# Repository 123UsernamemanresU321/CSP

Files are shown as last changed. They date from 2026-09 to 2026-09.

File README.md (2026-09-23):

# HEX-200 - detailed hexagonal piezoelectric tile concept

Revision A / 22 September 2026 / HBIS Collaborative Sciences Project

The regular hexagon is **200 mm across opposite flats**, 230.940 mm across
opposite corners and 50 mm high. This interpretation of “20 cm width” was an
explicit design assumption. The moving cover has a 2 mm downstroke.

## Start here

- `HEX_200_Interactive.html`: offline interactive 3D assembly. Open the downloaded
  file in a current desktop browser with WebGL 2. Rotate, zoom, inspect components,
  remove the cover, section the housing, separate components, or adjust the two
  illustrative motion controls. All scripts and meshes are embedded; no server
  or internet connection is required. File-preview apps may not execute HTML.
- `HEX_200_Technical_Design.pdf`: nine illustrated pages with dimensions, section,
  mechanism, calculations, circuit connections, materials, assembly and limits.
- `CAD/HEX_200_Assembly.step`: the editable solid assembly. **Units: millimetres.**
  This is the authoritative nominal shape representation.
- `HEX_200_Assembly.glb`: coloured visual 3D model. Its world scale is **metres**,
  as required by glTF. The root applies 0.001 to CAD coordinates in millimetres.
- `CAD/*.step`: representative individual components. Repeated parts are included
  at their first assembly location; the complete STEP contains every instance.
- `meshes/*.stl`: representative display / fit-study meshes in **mm**. Parts retain
  their assembly coordinates. These files do not qualify a printed part for loads.
- `CAD/Cover_Plate_Reference.dxf`: cover outline, 18 through holes and countersink
  reference circles in mm. Layer names distinguish through and reference geometry.
  This is a reference drawing, not a released laser/CNC job.
- `Cover_Hole_Coordinates.csv`: exact nominal XY coordinates of all 18 cover holes.
- `BOM.csv`, `parts_manifest.json`: 142 component records, materials and notes.
- `Electrical_Connections.csv`: reference circuit connectivity, not a SPICE model
  or PCB manufacturing file.
- `geometry_validation.json`: verification scope and nominal results.
- `figures/`: CAD-derived assembled, inside, exploded and cartridge renderings.

## Mechanism

The cover carries three PZT/brass bimorph beams. Their tip masses lag when the
cover accelerates, creating bending and an electrical response. Three springs
return the cover; six separate aluminium stop pillars carry the foot load after
2 mm of travel. Moving cages constrain relative tip motion. Three separate bridge
rectifiers feed a shared DC bus and a reference LTC3588-1 regulator circuit.

Cover stroke and beam deflection are independent quantities. The viewer’s beam
control is a geometric illustration, not a dynamic simulation or predicted
response. ±0.45 mm refers to total tip-centre displacement from the nominal flat
beam, including any static offset; it is not extra travel on top of gravity sag.

## Accuracy and verification

- All 142 CAD component shapes are valid in OpenCascade.
- The nominal rigid-part check found no unintended overlaps at rest or with the
  moving assembly 2 mm lower. Intended thread engagement, deforming bumper pads,
  wire routes and provisional PCB packages are excluded as stated in the report.
- The exact imported pan envelope measures 230.940107676 × 200 × 50 mm.
- Tip pitch at ±0.45 mm centre displacement leaves about 0.0765 mm nominal edge
  clearance. Manufacturing tolerances and dynamic impacts are not covered by that
  geometric result.
- The commercial bender is its published 63.5 × 31.8 × 0.51 mm mechanical envelope.
  Electrode and adhesive microgeometry is not reconstructed. Thread helices are
  omitted in the usual simplified fastener representations.
- Light visual meshes are decimated. Use STEP, not the visual meshes, for exact
  face/edge inspection. The renderings come from CAD triangles, not image generation.
- The viewer's JavaScript syntax and embedded mesh data were checked. A WebGL
  browser runtime was not available in the authoring environment, so live browser
  interactions were not independently executed there.

**This is an engineering concept for a CSP and bench development, not a fabrication
release or certified walkway product.** No measured electrical output, structural
load rating, fatigue life, slip class, acoustic performance or ingress rating is
claimed. The circuit board and electronic packages are placement references;
there are no Gerber files. Guide alignment, clamp preload, spring supply, wire
routing and seals require prototype qualification. A surrounding flush floor
mount / drainage arrangement is outside the single-tile scope.

## Rebuilding the CAD

The source was run with Python 3.12 and CadQuery 2.7.0:

```sh
python -m pip install -r source/requirements.txt
python source/build_tile.py
python source/check_geometry.py
```

This is a **fixed Rev A, dimensioned CAD construction script**. The exported
`parameters.json` records the design values; it is not an automatically consumed
configuration file. Changing just the width does not redesign the mechanisms.
Edit the coordinated dimensions in the script and repeat the clearance checks.
`build_tile.py` overwrites the generated geometry and BOM outputs.

Optional presentation rebuild, after regenerating the CAD:

```sh
python source/preview_meshes.py
python source/make_viewer.py
python source/render_raster.py
python source/make_report.py
```

The report script uses system DejaVu font paths; adjust them on other systems.
The DXF and connection CSV files in this release are independent reference
deliverables and are not regenerated by `build_tile.py`.

## References

1. [Piezo.com T220-A4BR-2513XB](https://piezo.com/products/piezoelectric-bending-transducer-t220-a4br-2513xb)
2. [Analog Devices LTC3588-1 datasheet](https://www.analog.com/media/en/technical-documentation/data-sheets/35881fc.pdf)
3. [Piezo.com mounting guidelines](https://support.piezo.com/article/126-mounting-guidelines)
4. [Piezo.com wiring guidelines](https://support.piezo.com/article/127-wiring-guidelines)

The user-supplied spring/cantilever sketch inspired the mechanism. Unspecified
dimensions, arrangement and protective details were designed for this request.

The embedded Three.js engine and pako library are MIT-licensed third-party tools;
their licences are included under `source/vendor/`.

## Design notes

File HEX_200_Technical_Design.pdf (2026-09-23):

HEX-200 / HBIS COLLABORATIVE SCIENCES PROJECT

# A complete tile, from tread to transducer

Regular hexagon • 200 mm across flats • 50 mm high • 2 mm cover stroke

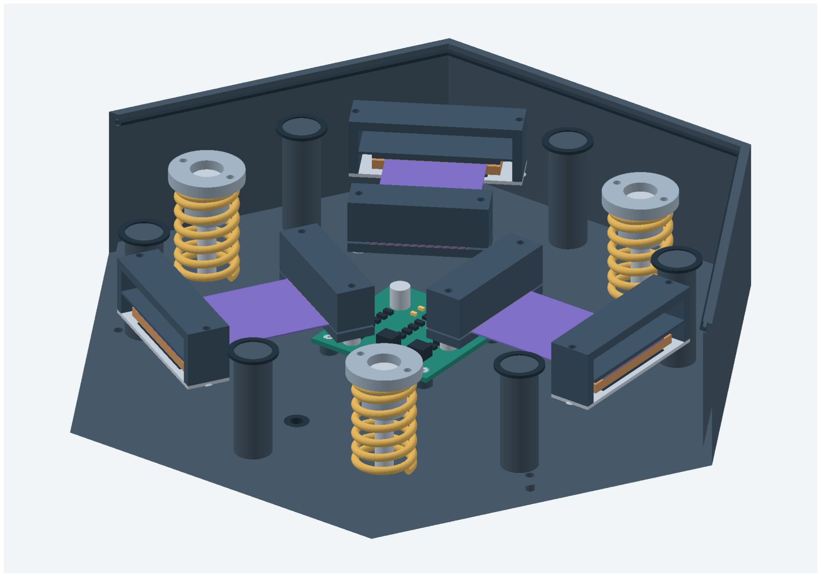
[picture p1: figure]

REV A • 22 SEPTEMBER 2026 • ALL CAD DIMENSIONS IN mm | 01 / 09 | ENGINEERING CONCEPT

### Based on your reference

The cover carries three piezoelectric cantilevers with tip masses. During a footstep, acceleration of the cover makes each mass lag and bends its beam.

### Two separate mechanical roles

Springs return the cover. Six structural stops transfer the main foot load to the pan after the cover moves 2 mm. The ceramic beams are not foot-load supports.

### What is defined

142 CAD components: housing, cover, tread, guide assemblies, springs, beam cartridges, limiters, fasteners, seals and a reference electronics bay.

### What accuracy means here

The STEP geometry and clearances are dimensioned. Spring specification, clamp details, PCB layout and load/energy performance still require prototype qualification.

Use for the CSP and bench development. This is a detailed engineering concept, not a certified floor tile or a fabrication release. The user reference is a schematic, so unspecified dimensions were designed here rather than inferred as measurements.

# Envelope and installation geometry

Plan and elevation at 1:2 when printed at 100% on A4 landscape; dimensions override display scaling.

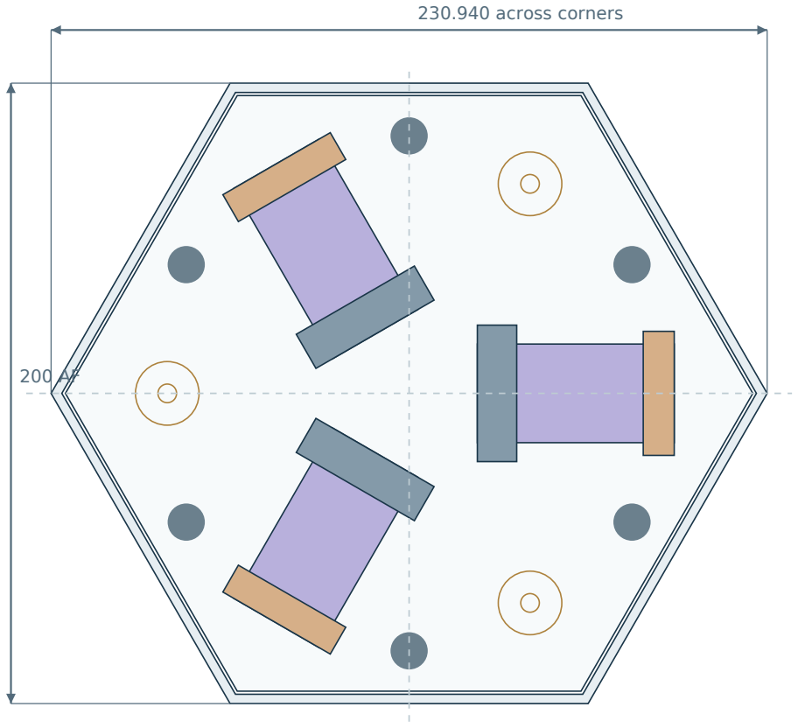
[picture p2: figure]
230.940 across corners

REV A • 22 SEPTEMBER 2026 • ALL CAD DIMENSIONS IN mm | 02 / 09 | ENGINEERING CONCEPT

PLAN - cover removed to show layout

50

ELEVATION - fixed rim defines overall height

Design dimension | Value
Width across flats | 200.000 mm
Width across corners | 230.940 mm
Hexagon side length | 115.470 mm
Housing wall / base | 3.0 / 5.0 mm
Cover AF / thickness | 192.0 / 6.0 mm
Tread thickness | 2.0 mm
Cover-to-wall clearance | 1.0 mm at each flat
Guide stations | R78; 60°, 180°, 300°
Beam axes | 0°, 120°, 240°
Structural stop stations | R83; 30° + n × 60°

Width assumption: “20 cm width” is interpreted as across opposite flats. A 200 mm corner-to-corner hexagon would be only 173.205 mm across flats and needs a redesigned internal layout.

# Section: the cover moves, the base stays fixed

Nominal undeformed geometry. Diagram shows the beam axis and opposite guide; strokes are not exaggerated.

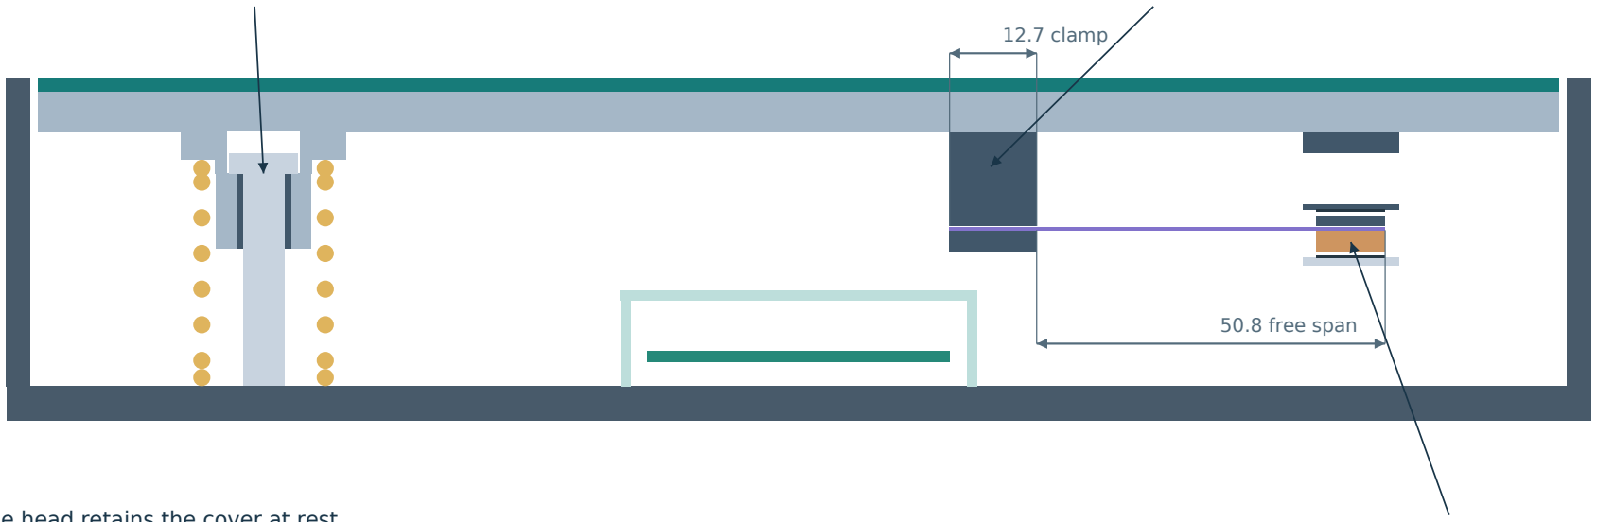
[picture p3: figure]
50.8 free span; 12.7 clamp

REV A • 22 SEPTEMBER 2026 • ALL CAD DIMENSIONS IN mm | 03 / 09 | ENGINEERING CONCEPT
Guided return assembly | Root moves with cover

Protected tip mass Guide head retains the cover at rest. 1.0 mm head clearance at full stroke.

Vertical datum | z at rest / mm
Underside of tile | 0.000
Pan floor surface | 5.000
Piezo mid-plane | 28.000
Spring upper seat | 38.000
Metal stop top | 40.000
Vertical datum | z at rest / mm
Bumper top | 40.500
Moving plate underside | 42.000
Plate upper surface | 48.000
Tread / fixed rim upper surface | 50.000
Plate underside after 2 mm stroke | 40.000

# Cantilever cartridge: three identical modules

Each cartridge is attached beneath the moving cover. All tip fasteners straddle the ceramic.

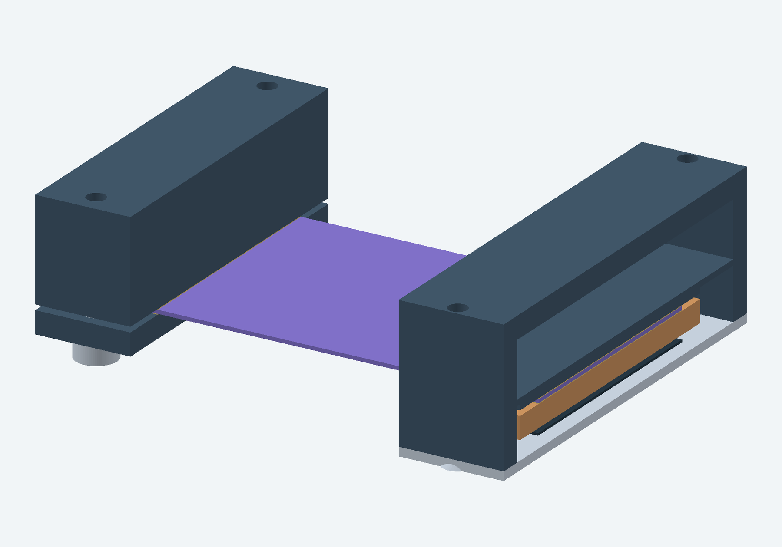
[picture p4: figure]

REV A • 22 SEPTEMBER 2026 • ALL CAD DIMENSIONS IN mm | 04 / 09 | ENGINEERING CONCEPT
Feature | Nominal
Beam envelope [1] | 63.5 × 31.8 × 0.51
Clamped length | 12.7
Free beam length | 50.8
Mass-centre lever arm | 45.8
Proof-mass blank | 10 × 40 × 3
Tip cap | 10 × 40 × 1.5
Electrical shims | 0.10 each side
Upper / lower flat gaps | 0.60 / 0.60
Visual tip-centre range | ±0.45

## A protective cage follows the cover

The upper and lower pads travel with the beam root. They limit relative mass motion; they do not define the 2 mm cover stroke. Screws are outside the beam edges, so no holes are drilled through PZT.

Tip rotation matters. With a 45.8 mm lever arm, a 0.45 mm centre displacement gives about 0.845° pitch. The minimum nominal edge clearance is about 0.0765 mm. This is a geometric check, not an impact or fatigue guarantee.

Source and modelling boundary
The selected reference bender is Piezo.com T220-A4BR-2513XB, a PZT 5A/brass bimorph [1]. It is modelled as its published external envelope. Internal adhesive/electrode thicknesses are not reverse-engineered. Clamp preload and permissible tip mass need supplier confirmation.

# Spring and beam calculations

Screening estimates for understanding and prototype selection; these are not measured output or strength results.

REV A • 22 SEPTEMBER 2026 • ALL CAD DIMENSIONS IN mm | 05 / 09 | ENGINEERING CONCEPT

## Cover return springs

Three custom target springs: wire diameter d = 2.5 mm; mean coil diameter D = 18 mm; five active turns, seven total turns; assumed shear modulus G = 79,000 N/mm². Free length 34 mm, installed length 33 mm.

### k = Gd⁴ / (8D³n) = 13.23 N/mm per spring

### K = 3k = 39.69 N/mm total

Idealised quantity | Value
Initial spring force (1 mm preload) | 39.69 N total
Spring force after 2 mm downstroke | 119.06 N total
Additional force over the stroke | 79.37 N
Minimum spring length at full stroke | 31 mm
Approximate solid length, 7 × 2.5 | 17.5 mm
Increase in stored spring energy | 0.159 J

Spring force is not the net foot force: the moving assembly weight and seal friction also act. Most walking loads will bring this low-travel design onto its stops. Springs store and return mechanical energy; that stored energy is not an electrical-output prediction.

## Mass-loaded piezoelectric beam

Use a first-mode model about the gravity-deflected equilibrium: m q̈ + c q̇ + kq + electrical coupling = −m ÿ
Here y is cover motion and q is mass motion relative to the cover. Cover acceleration drives the beam.

For an illustrative estimate, assume the supplier’s quoted stiffness of 0.388 N/mm applies to a 50.8 mm free span [1]. Moving the force application to 45.8 mm gives k ≈ 0.388(50.8/45.8)³ ≈ 0.530 N/mm. This mounting assumption must be checked.

A 9.60 g steel mass blank plus cap/fasteners and effective beam mass gives roughly 12 g effective modal mass. Then f ≈ (1/2π)√(k/m) ≈ 33 Hz. Estimated static sag is around 0.2 mm; CAD is shown flat before sag.

A walking cadence of a few steps per second does not continuously excite a 33 Hz resonance. The idea relies on the acceleration transient and subsequent vibration. Actual damping and the circuit strongly affect how much energy is collected.

Required measurement: use the measured capacitance and ΔE = ½C(Vf² − Vi²), then divide by counted activations. Subtract leakage and account for any load current.

# Electrical architecture and connectivity

A complete reference topology with provisional board placement; not a routed or fabrication-ready PCB.

REV A • 22 SEPTEMBER 2026 • ALL CAD DIMENSIONS IN mm | 06 / 09 | ENGINEERING CONCEPT
PZT beam 1 | Bridge 1: 4 diodes
PZT beam 2 | Bridge 2: 4 diodes
PZT beam 3 | Bridge 3: 4 diodes

Rectified DC bus

CIN: 47 µF effective
≥35 V; low leakage

LTC3588-1

3.3 V target

COUT

47 µF

≥6.3 V

Why one rectifier per beam? The three beams need not vibrate in phase. Rectifying separately before joining the DC outputs avoids directly opposing their AC voltages. The LTC3588-1 internal bridge is bypassed here; the external DC bus feeds VIN. Verify this implementation and leakage on a bench [2].

Connection | Reference design
Each bridge, AC terminals A/B | D1: A → DC+; D2: B → DC+; D3: GND → A; D4: GND → B. Arrows denote anode → cathode.
Regulator input / unused AC inputs | VIN to rectified DC+; ground/exposed pad to GND. PZ1 and PZ2 left unconnected.
Buck and output | SW → 10 µH inductor → VOUT; COUT between VOUT and GND; PGOOD available at test pad.
Rail capacitors / voltage selection | 1 µF CAP-to-VIN; 4.7 µF VIN2-to-GND. D1 tied to VIN2, D0 to GND for 3.3 V.
Qualification points | Measure diode leakage, capacitor effective C and cold start. Allow for nominal ~5.05 V start-up at 3.3 V setting [2].

No battery is fitted. A low-duty-cycle sensor or switched LED is a candidate load only after energy measurement. The 44 × 44 mm board, parts and hood are mechanical placement envelopes; footprints, routing and exact capacitor packages remain provisional.

# Materials and bill of materials

All 142 individual components are listed in BOM.csv and selectable in the 3D viewer.

REV A • 22 SEPTEMBER 2026 • ALL CAD DIMENSIONS IN mm | 07 / 09 | ENGINEERING CONCEPT
Assembly / quantity | Material and function
1 housing with 6 integral stops | 6061-T6 aluminium. 5 mm base, 3 mm sidewalls. Stops end at z40.
1 cover + 1 tread | 6 mm aluminium load spreader; 2 mm replaceable EPDM tread.
3 guide sets | Steel headed guide, aluminium spring-seat cup, POM sleeve.
3 return springs | Custom spring-steel targets; 2.5 mm wire / 18 mm mean diameter.
3 piezoelectric beams | Reference PZT 5A/brass bimorphs; supplier external dimensions [1].
3 root clamp sets | POM tower + clamp shoe; polyimide electrical isolation.
3 proof-mass sets | Stainless steel mass + POM cap + isolating shims.
3 limiter cages | POM cage, removable steel bottom, two EPDM stop pads.
Assembly / quantity | Material and function
6 stop bumper rings | EPDM; nominal compression 0.5 mm at full stroke.
1 wiper + 1 cable grommet | EPDM lip in the sidewall groove; underside cable port.
1 PCB + splash hood | FR4 reference board; polycarbonate hood bonded to pan.
18 cover screws | M3 countersunk reference geometry.
3 guide anchor screws | M4 countersunk nominal custom-length envelopes.
6 root / 6 tip screws | M3 root clamp / M2 tip clamp screws.
6 cage + 4 PCB screws | M2 nominal hardware envelopes.
Wires and electrical components | Fine flexible leads, three bridge rectifiers, regulator, capacitors, inductor and connectors.

## Material choices for the library corridor

The proposed rubber tread, polymer guide liners and buffered stops address contact noise, but their acoustic benefit has not been measured. A wipeable lip and drained pan address incidental water; the hood protects electronics only if its bond and feedthroughs are qualified.

Bio-based polymer samples can be investigated for removable cosmetic parts. This revision uses aluminium for the structural cover and stops because no creep, impact or moisture data have been supplied for a bioplastic formulation. Printed PLA copies are display models, not step-on products.

# Assembly sequence and fit control

Prototype workflow. Dimensions are nominal; fit tolerances below are proposed targets requiring manufacturing review.

REV A • 22 SEPTEMBER 2026 • ALL CAD DIMENSIONS IN mm | 08 / 09 | ENGINEERING CONCEPT

1

### Prepare the pan

Machine the pocket, six stop pillars, wiper groove, drain holes and anchor bores. Deburr all edges; verify the six stop tops are coplanar.

2

### Build the three cartridges

Fit insulating shims, root clamps and tip clamps. Keep fasteners outside the ceramic. Fit the limiter cages; confirm the top/bottom gaps optically.

3

### Install captive guides

Insert each headed guide through its cup and sleeve. Seat springs and guides on the pan. Hold each guide in a fixture while securing its underside anchor screw.

4

### Fit electronics and wiring

Assemble and bench-test the circuit separately. Install the board/hood and route flexible service loops clear of springs, beam spans and cage stops.

5

### Close the tile

Lower the cartridge-loaded cover onto the three guide-cup flanges and secure its top screws. Verify return and retention. Fit the wiper and replaceable tread.

6

### Qualify on a fixture

Use controlled mechanical loading on the bench. Check return motion, edge loading, electrical output and repeated cycling before considering foot use.

Fit / feature | Proposed target
Aluminium noncritical dimensions | ±0.10 mm
Polymer noncritical dimensions | ±0.15 mm; account for temperature/moisture
Stop top height / coplanarity | 40.00 ±0.05 mm / within 0.05 mm
Guide shaft / sleeve bore | Ø6.00 −0.01/0; bore Ø6.10 +0.02/0
Radial guide clearance | 0.050 to 0.065 mm, before alignment effects
Tip stop gaps | 0.60 ±0.05 mm; measure assembled
Cover clearance at flats | 1.0 mm nominal each side
Thread geometry | Tap sizes / thread classes set at manufacture; STEP threads are simplified

Assembly access matters. Lower guide-anchor screws are accessed from the underside. Cage bottoms are removable for beam service. Cover screws are accessed after peeling or removing the tread. The floor installation must allow the tile to be removed.

Supplier clamp instructions [3] are useful background, but their torque values do not automatically apply to these custom POM clamps. Establish preload experimentally with the actual beam and shims.

# What has been checked, and what comes next

The CAD is inspectable and editable. Precision of geometry must not be mistaken for proven floor performance.

REV A • 22 SEPTEMBER 2026 • ALL CAD DIMENSIONS IN mm | 09 / 09 | ENGINEERING CONCEPT
Check | Result / boundary
Solid validity | 142 components valid in OpenCascade.
Nominal rigid interference | No unintended overlaps found at rest or at 2 mm cover stroke.
Envelope | 200.000 mm flats; 230.940 mm corners; 50.000 mm height.
Tip pitch at ±0.45 mm | Nominal minimum edge gap ≈0.0765 mm.
Excluded from rigid verdict | Thread engagement envelopes, PCB packages and indicative wire routing.
Not yet performed | FEA, local heel/edge loads, fatigue, wear, ingress/slip/acoustic tests or electrical-output tests.

## Before any real corridor installation

Verify local cover bending, off-centre loading and guide binding; qualify the beam clamps, tip-mass retention and overtravel impacts. Check wet grip, raised-edge hazards, liquid paths and a removable flush mounting frame. No pedestrian load rating or IP rating is claimed.

## Open the package

HTML: open HEX_200_Interactive.html in a current desktop browser; all viewer resources are embedded.
CAD: import CAD/HEX_200_Assembly.step in millimetres. Individual representative parts are included.
STL: units are mm; meshes are for visualisation/display prototypes.
Source: build_tile.py rebuilds the fixed Rev A design. Editing the width alone does not automatically redesign the mechanism.

## Sources and provenance

[1] Piezo.com, T220-A4BR-2513XB

Published external dimensions, PZT 5A/brass construction and stiffness reference. Accessed 22 September 2026.

https://piezo.com/products/piezoelectric-bending-transducer-t220-a4br-2513xb

[2] Analog Devices, LTC3588-1 datasheet

Reference regulator connections and start-up behaviour. The proposed three-bridge circuit and board arrangement are this design’s engineering choices.

https://www.analog.com/media/en/technical-documentation/data-sheets/35881fc.pdf

[3] Piezo.com, Mounting Guidelines

Background on clamp practice and fixing security. Commercial-kit torque recommendations are not adopted for the custom clamps.

https://support.piezo.com/article/126-mounting-guidelines

[4] Piezo.com, Wiring Guidelines

Background on electrode connection and lead strain relief. Exact terminations need qualification with the purchased device.

https://support.piezo.com/article/127-wiring-guidelines

Original work: hexagonal geometry, spatial arrangement, spring target, captive guides, protective cages, clearances, diagrams and CAD were developed for this request. The supplied sketch inspired the mechanism; it did not provide a complete specification. Renders are derived from CAD, not AI-generated pictures.

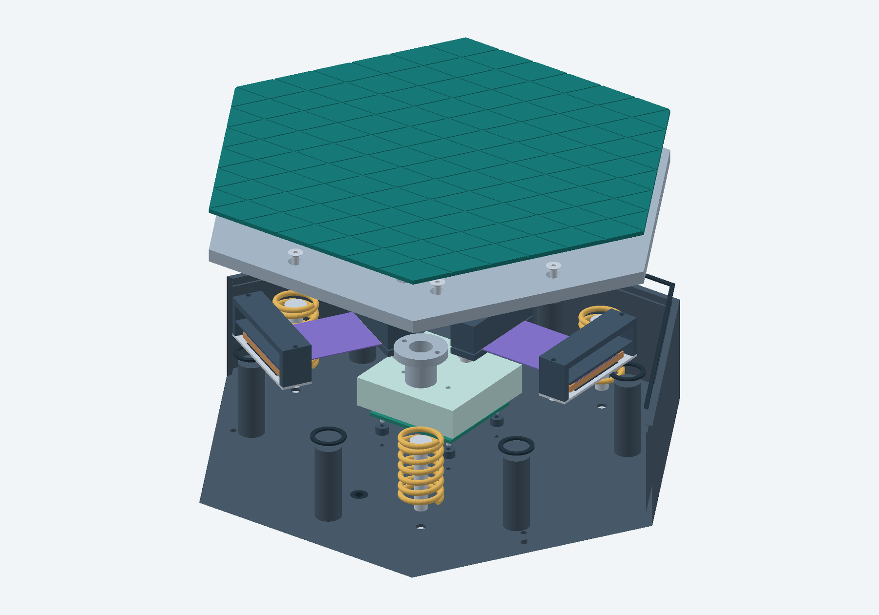
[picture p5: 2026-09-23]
figures/Tile_Exploded.png

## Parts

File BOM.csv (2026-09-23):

ID | Component | Material | Motion | Volume mm^3 | Notes
A01 | Housing and six structural stops | 6061-T6 aluminium | fixed | 286965.327 | CNC concept; six integral Ø12 stops finish at z40. Three Ø3 weeps; underside cable port.
A02 | Perimeter sliding wiper | EPDM | fixed | 1344.071 | Nominal lip envelope in 2 mm groove; friction and water ingress unqualified.
A03_1 | Stop bumper ring | EPDM | fixed | 87.965 | Contact at 1.50 mm stroke; compress 0.50 mm before metal stop.
A03_2 | Stop bumper ring | EPDM | fixed | 87.965 | Contact at 1.50 mm stroke; compress 0.50 mm before metal stop.
A03_3 | Stop bumper ring | EPDM | fixed | 87.965 | Contact at 1.50 mm stroke; compress 0.50 mm before metal stop.
A03_4 | Stop bumper ring | EPDM | fixed | 87.965 | Contact at 1.50 mm stroke; compress 0.50 mm before metal stop.
A03_5 | Stop bumper ring | EPDM | fixed | 87.965 | Contact at 1.50 mm stroke; compress 0.50 mm before metal stop.
A03_6 | Stop bumper ring | EPDM | fixed | 87.965 | Contact at 1.50 mm stroke; compress 0.50 mm before metal stop.
A04 | Underside cable grommet | EPDM | fixed | 188.496 | Cable exits underside into a receiving recess; cable itself excluded from rigid envelope.
A10 | Moving load-spreading plate | 6061-T6 aluminium | cover | 190202.682 | 18 countersunk M3 fixing holes; 1.00 mm side clearance to pan.
A11 | Replaceable textured tread | EPDM rubber | cover | 62446.468 | 2 mm nominal including adhesive allowance; grooves 0.35 mm deep. Slip resistance untested.
F01_1 | Cover mounting screw M3 x 10 | Stainless steel | cover | 89.703 | Thread envelope; no helical threads.
F01_2 | Cover mounting screw M3 x 10 | Stainless steel | cover | 89.703 | Thread envelope; no helical threads.
F01_3 | Cover mounting screw M3 x 10 | Stainless steel | cover | 89.703 | Thread envelope; no helical threads.
F01_4 | Cover mounting screw M3 x 10 | Stainless steel | cover | 89.703 | Thread envelope; no helical threads.
F01_5 | Cover mounting screw M3 x 10 | Stainless steel | cover | 89.703 | Thread envelope; no helical threads.
F01_6 | Cover mounting screw M3 x 10 | Stainless steel | cover | 89.703 | Thread envelope; no helical threads.
F01_7 | Cover mounting screw M3 x 10 | Stainless steel | cover | 89.703 | Thread envelope; no helical threads.
F01_8 | Cover mounting screw M3 x 10 | Stainless steel | cover | 89.703 | Thread envelope; no helical threads.
F01_9 | Cover mounting screw M3 x 10 | Stainless steel | cover | 89.703 | Thread envelope; no helical threads.
F01_10 | Cover mounting screw M3 x 10 | Stainless steel | cover | 89.703 | Thread envelope; no helical threads.
F01_11 | Cover mounting screw M3 x 10 | Stainless steel | cover | 89.703 | Thread envelope; no helical threads.
F01_12 | Cover mounting screw M3 x 10 | Stainless steel | cover | 89.703 | Thread envelope; no helical threads.
F01_13 | Cover mounting screw M3 x 10 | Stainless steel | cover | 89.703 | Thread envelope; no helical threads.
F01_14 | Cover mounting screw M3 x 10 | Stainless steel | cover | 89.703 | Thread envelope; no helical threads.
F01_15 | Cover mounting screw M3 x 10 | Stainless steel | cover | 89.703 | Thread envelope; no helical threads.
F01_16 | Cover mounting screw M3 x 10 | Stainless steel | cover | 89.703 | Thread envelope; no helical threads.
F01_17 | Cover mounting screw M3 x 10 | Stainless steel | cover | 89.703 | Thread envelope; no helical threads.
F01_18 | Cover mounting screw M3 x 10 | Stainless steel | cover | 89.703 | Thread envelope; no helical threads.
G01_1 | Captive guide and return retainer | Stainless steel | fixed | 1043.7 | Ø6 shaft, Ø10 head; lower M4 female thread. Head underside at z36 sets rest height.
G02_1 | Sliding guide cup and spring seat | 6061-T6 aluminium | cover | 2689.078 | Ø8 liner seat; Ø10.60 head pocket. Four-mm flange seats spring at z38.
G03_1 | Replaceable guide liner | POM | cover | 231.449 | Ø8 outside / Ø6.10 inside / 11 long. Nominal mating fit; retention to be qualified.
S01_1 | Return spring | Spring steel | spring | 1943.5 | Custom target: wire 2.5, mean Ø18, 5 active / 7 total turns, free 34, installed 33 mm.
F02_1 | Guide anchor countersunk M4 x 11 envelope | Stainless steel | fixed | 184.675 | Custom nominal length envelope; engagement is 6 mm into guide. Threads simplified.
G01_2 | Captive guide and return retainer | Stainless steel | fixed | 1043.7 | Ø6 shaft, Ø10 head; lower M4 female thread. Head underside at z36 sets rest height.
G02_2 | Sliding guide cup and spring seat | 6061-T6 aluminium | cover | 2689.078 | Ø8 liner seat; Ø10.60 head pocket. Four-mm flange seats spring at z38.
G03_2 | Replaceable guide liner | POM | cover | 231.449 | Ø8 outside / Ø6.10 inside / 11 long. Nominal mating fit; retention to be qualified.
S01_2 | Return spring | Spring steel | spring | 1943.5 | Custom target: wire 2.5, mean Ø18, 5 active / 7 total turns, free 34, installed 33 mm.
F02_2 | Guide anchor countersunk M4 x 11 envelope | Stainless steel | fixed | 184.675 | Custom nominal length envelope; engagement is 6 mm into guide. Threads simplified.
G01_3 | Captive guide and return retainer | Stainless steel | fixed | 1043.7 | Ø6 shaft, Ø10 head; lower M4 female thread. Head underside at z36 sets rest height.
G02_3 | Sliding guide cup and spring seat | 6061-T6 aluminium | cover | 2689.078 | Ø8 liner seat; Ø10.60 head pocket. Four-mm flange seats spring at z38.
G03_3 | Replaceable guide liner | POM | cover | 231.449 | Ø8 outside / Ø6.10 inside / 11 long. Nominal mating fit; retention to be qualified.
S01_3 | Return spring | Spring steel | spring | 1943.5 | Custom target: wire 2.5, mean Ø18, 5 active / 7 total turns, free 34, installed 33 mm.
F02_3 | Guide anchor countersunk M4 x 11 envelope | Stainless steel | fixed | 184.675 | Custom nominal length envelope; engagement is 6 mm into guide. Threads simplified.
H01_1 | Cantilever root tower | POM | cover | 7525.719 | Top and bottom blind threaded bores stay separate. Clamp screws sit outside piezo width.
H02_1 | Removable lower clamp | POM | cover | 1621.925
H031_1 | Root electrical isolation shim | Polyimide | cover | 40.386 | 0.10 mm nominal; supplier must approve clamp construction.
H032_1 | Root electrical isolation shim | Polyimide | cover | 40.386 | 0.10 mm nominal; supplier must approve clamp construction.
P01_1 | PZT 5A bimorph | PZT / brass laminate | beam | 1029.843 | T220-A4BR-2513XB mechanical envelope. Free length 50.8 mm. Nominal flat, before gravity sag.
H04_1 | Tip proof mass | Stainless steel | tip | 1187.936 | 10 x 40 x 3 blank = 9.60 g before two tapped holes; actual CAD volume in BOM.
H05_1 | Insulated tip clamp cap | POM | tip | 579.705
H061_1 | Tip electrical isolation shim | Polyimide | tip | 31.8
H062_1 | Tip electrical isolation shim | Polyimide | tip | 31.8
F031_1 | Root clamp M3 x 8 | Stainless steel | cover | 108.581
F032_1 | Root clamp M3 x 8 | Stainless steel | cover | 108.581
F041_1 | Tip clamp M2 x 5 | Stainless steel | tip | 19.262
F042_1 | Tip clamp M2 x 5 | Stainless steel | tip | 19.262
H07_1 | Relative travel limiter cage | POM | cover | 4031.548 | Upper catch, two side walls, mounting flange. These move with the cover.
H08_1 | Removable cage bottom | Stainless steel | cover | 889.726
H09_1 | Lower tip stop pad | EPDM | cover | 96.0 | 0.60 mm nominal gap from metal proof-mass underside.
H10_1 | Upper tip stop pad | EPDM | cover | 96.0 | 0.60 mm nominal gap above cap; pitch reduces usable edge clearance.
F051_1 | Cage closure M2 countersunk | Stainless steel | cover | 18.86
F052_1 | Cage closure M2 countersunk | Stainless steel | cover | 18.86
H01_2 | Cantilever root tower | POM | cover | 7525.719 | Top and bottom blind threaded bores stay separate. Clamp screws sit outside piezo width.
H02_2 | Removable lower clamp | POM | cover | 1621.925
H031_2 | Root electrical isolation shim | Polyimide | cover | 40.386 | 0.10 mm nominal; supplier must approve clamp construction.
H032_2 | Root electrical isolation shim | Polyimide | cover | 40.386 | 0.10 mm nominal; supplier must approve clamp construction.
P01_2 | PZT 5A bimorph | PZT / brass laminate | beam | 1029.843 | T220-A4BR-2513XB mechanical envelope. Free length 50.8 mm. Nominal flat, before gravity sag.
H04_2 | Tip proof mass | Stainless steel | tip | 1187.936 | 10 x 40 x 3 blank = 9.60 g before two tapped holes; actual CAD volume in BOM.
H05_2 | Insulated tip clamp cap | POM | tip | 579.705
H061_2 | Tip electrical isolation shim | Polyimide | tip | 31.8
H062_2 | Tip electrical isolation shim | Polyimide | tip | 31.8
F031_2 | Root clamp M3 x 8 | Stainless steel | cover | 108.581
F032_2 | Root clamp M3 x 8 | Stainless steel | cover | 108.581
F041_2 | Tip clamp M2 x 5 | Stainless steel | tip | 19.262
F042_2 | Tip clamp M2 x 5 | Stainless steel | tip | 19.262
H07_2 | Relative travel limiter cage | POM | cover | 4031.548 | Upper catch, two side walls, mounting flange. These move with the cover.
H08_2 | Removable cage bottom | Stainless steel | cover | 889.726
H09_2 | Lower tip stop pad | EPDM | cover | 96.0 | 0.60 mm nominal gap from metal proof-mass underside.
H10_2 | Upper tip stop pad | EPDM | cover | 96.0 | 0.60 mm nominal gap above cap; pitch reduces usable edge clearance.
F051_2 | Cage closure M2 countersunk | Stainless steel | cover | 18.86
F052_2 | Cage closure M2 countersunk | Stainless steel | cover | 18.86
H01_3 | Cantilever root tower | POM | cover | 7525.719 | Top and bottom blind threaded bores stay separate. Clamp screws sit outside piezo width.
H02_3 | Removable lower clamp | POM | cover | 1621.925
H031_3 | Root electrical isolation shim | Polyimide | cover | 40.386 | 0.10 mm nominal; supplier must approve clamp construction.
H032_3 | Root electrical isolation shim | Polyimide | cover | 40.386 | 0.10 mm nominal; supplier must approve clamp construction.
P01_3 | PZT 5A bimorph | PZT / brass laminate | beam | 1029.843 | T220-A4BR-2513XB mechanical envelope. Free length 50.8 mm. Nominal flat, before gravity sag.
H04_3 | Tip proof mass | Stainless steel | tip | 1187.936 | 10 x 40 x 3 blank = 9.60 g before two tapped holes; actual CAD volume in BOM.
H05_3 | Insulated tip clamp cap | POM | tip | 579.705
H061_3 | Tip electrical isolation shim | Polyimide | tip | 31.8
H062_3 | Tip electrical isolation shim | Polyimide | tip | 31.8
F031_3 | Root clamp M3 x 8 | Stainless steel | cover | 108.581
F032_3 | Root clamp M3 x 8 | Stainless steel | cover | 108.581
F041_3 | Tip clamp M2 x 5 | Stainless steel | tip | 19.262
F042_3 | Tip clamp M2 x 5 | Stainless steel | tip | 19.262
H07_3 | Relative travel limiter cage | POM | cover | 4031.548 | Upper catch, two side walls, mounting flange. These move with the cover.
H08_3 | Removable cage bottom | Stainless steel | cover | 889.726
H09_3 | Lower tip stop pad | EPDM | cover | 96.0 | 0.60 mm nominal gap from metal proof-mass underside.
H10_3 | Upper tip stop pad | EPDM | cover | 96.0 | 0.60 mm nominal gap above cap; pitch reduces usable edge clearance.
F051_3 | Cage closure M2 countersunk | Stainless steel | cover | 18.86
F052_3 | Cage closure M2 countersunk | Stainless steel | cover | 18.86
E01 | Reference PCB | FR4 | fixed | 3060.956 | 44 x 44 x 1.6. Placement concept only: not routed, no Gerbers or component procurement claim.
E02_1 | PCB standoff | POM | fixed | 86.838
F06_1 | PCB screw M2 x 6 | Stainless steel | fixed | 21.356
E02_2 | PCB standoff | POM | fixed | 86.838
F06_2 | PCB screw M2 x 6 | Stainless steel | fixed | 21.356
E02_3 | PCB standoff | POM | fixed | 86.838
F06_3 | PCB screw M2 x 6 | Stainless steel | fixed | 21.356
E02_4 | PCB standoff | POM | fixed | 86.838
F06_4 | PCB screw M2 x 6 | Stainless steel | fixed | 21.356
E03 | Electronics splash hood | Polycarbonate | fixed | 7816.357 | Open bottom bonded to pan; four potted wire holes. Mechanical envelope, ingress performance untested.
E04_1 | Two-pin piezo connector envelope | Connector envelope | fixed | 120.0 | Package and board layout remain provisional.
E05_1_0 | Rectifier diode envelope | Semiconductor envelope | fixed | 6.48
E05_1_1 | Rectifier diode envelope | Semiconductor envelope | fixed | 6.48
E05_1_2 | Rectifier diode envelope | Semiconductor envelope | fixed | 6.48
E05_1_3 | Rectifier diode envelope | Semiconductor envelope | fixed | 6.48
E04_2 | Two-pin piezo connector envelope | Connector envelope | fixed | 120.0 | Package and board layout remain provisional.
E05_2_0 | Rectifier diode envelope | Semiconductor envelope | fixed | 6.48
E05_2_1 | Rectifier diode envelope | Semiconductor envelope | fixed | 6.48
E05_2_2 | Rectifier diode envelope | Semiconductor envelope | fixed | 6.48
E05_2_3 | Rectifier diode envelope | Semiconductor envelope | fixed | 6.48
E04_3 | Two-pin piezo connector envelope | Connector envelope | fixed | 120.0 | Package and board layout remain provisional.
E05_3_0 | Rectifier diode envelope | Semiconductor envelope | fixed | 6.48
E05_3_1 | Rectifier diode envelope | Semiconductor envelope | fixed | 6.48
E05_3_2 | Rectifier diode envelope | Semiconductor envelope | fixed | 6.48
E05_3_3 | Rectifier diode envelope | Semiconductor envelope | fixed | 6.48
E06 | LTC3588-1 package envelope | DFN envelope | fixed | 9.0
E07 | 10 uH inductor envelope | Inductor envelope | fixed | 48.0
E08 | 47 uF input capacitor envelope | Capacitor envelope | fixed | 225.189
E09 | 47 uF output capacitor envelope | Capacitor envelope | fixed | 98.175
E10 | Output connector envelope | Connector envelope | fixed | 120.0
E11_1 | Passives envelope | Passive envelope | fixed | 2.5
E11_2 | Passives envelope | Passive envelope | fixed | 2.5
E11_3 | Passives envelope | Passive envelope | fixed | 2.5
E11_4 | Passives envelope | Passive envelope | fixed | 2.5
W01_1_0 | Flexible piezo lead | Insulated fine wire | wire | 54.164 | Routing envelope; two electrode terminations and service-loop attachment need bench finalisation.
W01_1_1 | Flexible piezo lead | Insulated fine wire | wire | 54.974 | Routing envelope; two electrode terminations and service-loop attachment need bench finalisation.
W01_2_0 | Flexible piezo lead | Insulated fine wire | wire | 64.117 | Routing envelope; two electrode terminations and service-loop attachment need bench finalisation.
W01_2_1 | Flexible piezo lead | Insulated fine wire | wire | 51.926 | Routing envelope; two electrode terminations and service-loop attachment need bench finalisation.
W01_3_0 | Flexible piezo lead | Insulated fine wire | wire | 51.479 | Routing envelope; two electrode terminations and service-loop attachment need bench finalisation.
W01_3_1 | Flexible piezo lead | Insulated fine wire | wire | 43.959 | Routing envelope; two electrode terminations and service-loop attachment need bench finalisation.
W02 | Output cable routing | Insulated cable | fixed | 527.911 | Schematic route; cable termination and strain relief to be finalised.

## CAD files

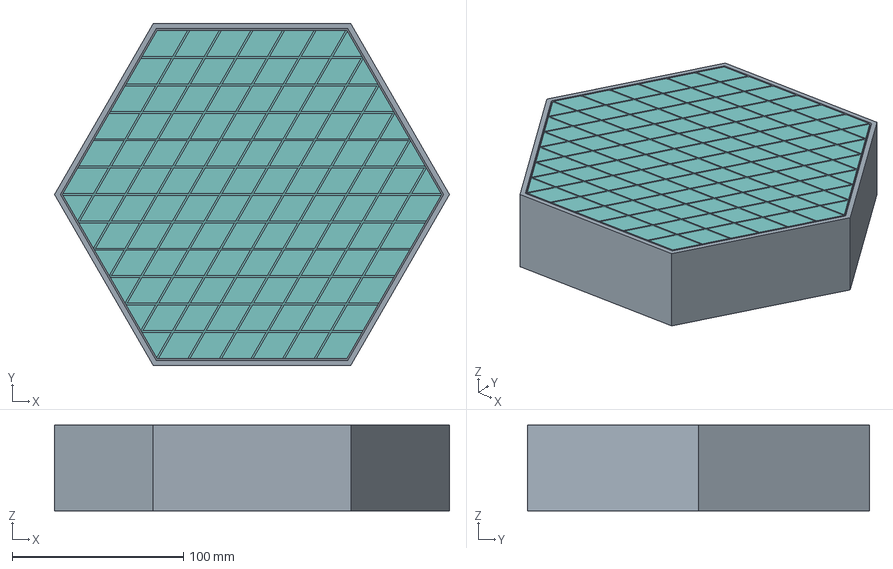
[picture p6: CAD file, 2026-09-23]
CAD/HEX_200_Assembly.step
230.9 x 200.0 x 50.0 mm
A01_Housing_and_six_structural_stops
A02_Perimeter_sliding_wiper
A03_1_Stop_bumper_ring
A03_2_Stop_bumper_ring
A03_3_Stop_bumper_ring
A03_4_Stop_bumper_ring
A03_5_Stop_bumper_ring
A03_6_Stop_bumper_ring
A04_Underside_cable_grommet
A10_Moving_load-spreading_plate
A11_Replaceable_textured_tread
F01_1_Cover_mounting_screw_M3_x_10
F01_2_Cover_mounting_screw_M3_x_10
F01_3_Cover_mounting_screw_M3_x_10
F01_4_Cover_mounting_screw_M3_x_10
F01_5_Cover_mounting_screw_M3_x_10
F01_6_Cover_mounting_screw_M3_x_10
F01_7_Cover_mounting_screw_M3_x_10
F01_8_Cover_mounting_screw_M3_x_10
F01_9_Cover_mounting_screw_M3_x_10
F01_10_Cover_mounting_screw_M3_x_10
F01_11_Cover_mounting_screw_M3_x_10
F01_12_Cover_mounting_screw_M3_x_10
F01_13_Cover_mounting_screw_M3_x_10
F01_14_Cover_mounting_screw_M3_x_10
F01_15_Cover_mounting_screw_M3_x_10
F01_16_Cover_mounting_screw_M3_x_10
F01_17_Cover_mounting_screw_M3_x_10
F01_18_Cover_mounting_screw_M3_x_10
G01_1_Captive_guide_and_return_retainer
G02_1_Sliding_guide_cup_and_spring_seat
G03_1_Replaceable_guide_liner
S01_1_Return_spring
F02_1_Guide_anchor_countersunk_M4_x_11_envelope
G01_2_Captive_guide_and_return_retainer
G02_2_Sliding_guide_cup_and_spring_seat
G03_2_Replaceable_guide_liner
S01_2_Return_spring
F02_2_Guide_anchor_countersunk_M4_x_11_envelope
G01_3_Captive_guide_and_return_retainer
G02_3_Sliding_guide_cup_and_spring_seat
G03_3_Replaceable_guide_liner
S01_3_Return_spring
F02_3_Guide_anchor_countersunk_M4_x_11_envelope
H01_1_Cantilever_root_tower
H02_1_Removable_lower_clamp
H031_1_Root_electrical_isolation_shim
H032_1_Root_electrical_isolation_shim
P01_1_PZT_5A_bimorph
H04_1_Tip_proof_mass
H05_1_Insulated_tip_clamp_cap
H061_1_Tip_electrical_isolation_shim
H062_1_Tip_electrical_isolation_shim
F031_1_Root_clamp_M3_x_8
F032_1_Root_clamp_M3_x_8
F041_1_Tip_clamp_M2_x_5
F042_1_Tip_clamp_M2_x_5
H07_1_Relative_travel_limiter_cage
H08_1_Removable_cage_bottom
H09_1_Lower_tip_stop_pad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

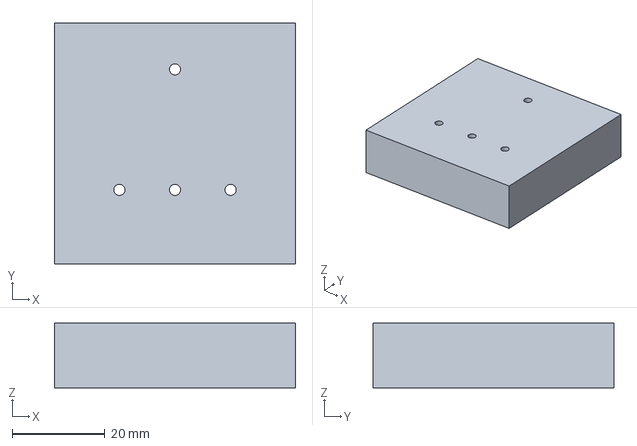
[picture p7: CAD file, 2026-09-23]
CAD/E03.step
52.0 x 52.0 x 14.0 mm

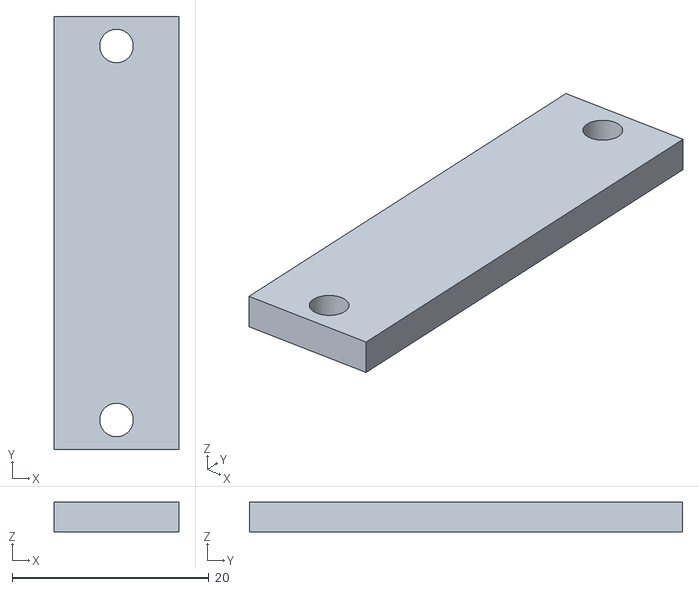
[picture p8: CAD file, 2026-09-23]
meshes/H02_1.stl
12.7 x 44.0 x 3.00

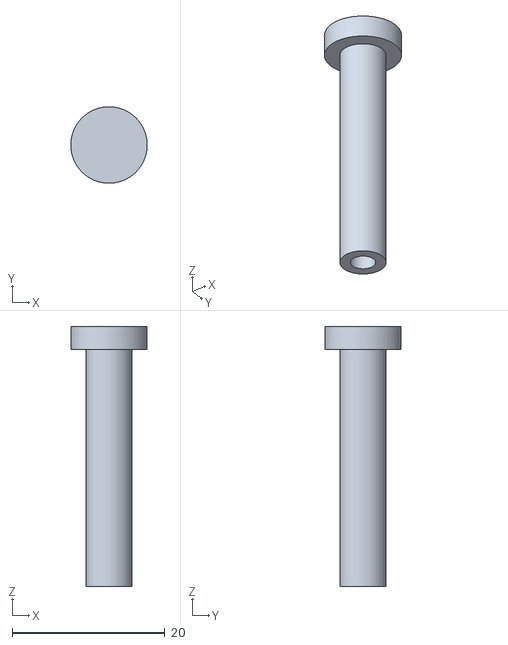
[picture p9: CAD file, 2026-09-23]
meshes/G01_1.stl
10.00 x 10.00 x 34.0

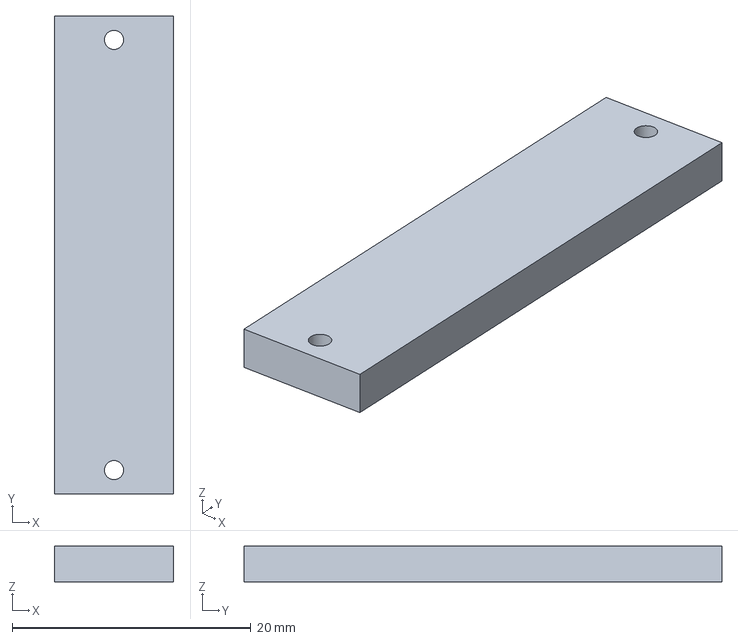
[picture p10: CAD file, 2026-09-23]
CAD/H04_1.step
10.0 x 40.0 x 3.00 mm

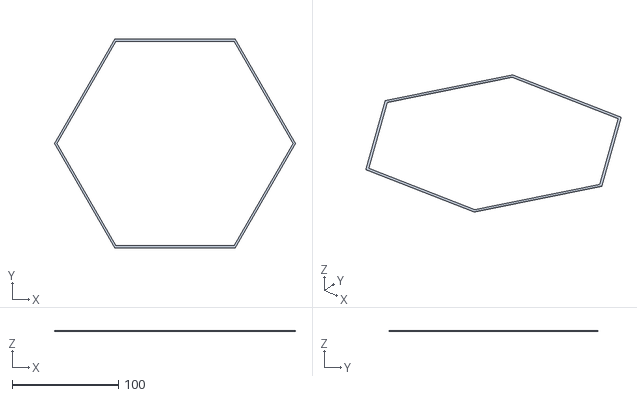
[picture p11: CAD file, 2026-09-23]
meshes/A02.stl
226.3 x 196.0 x 1.00

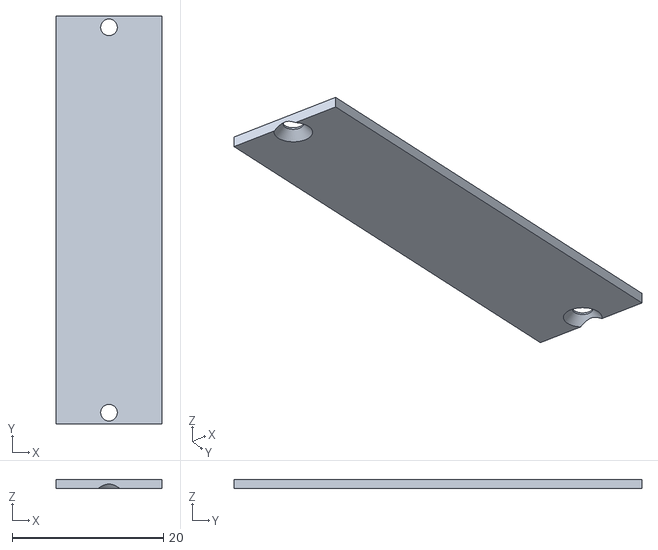
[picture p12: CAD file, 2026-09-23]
meshes/H08_1.stl
14.0 x 54.0 x 1.20

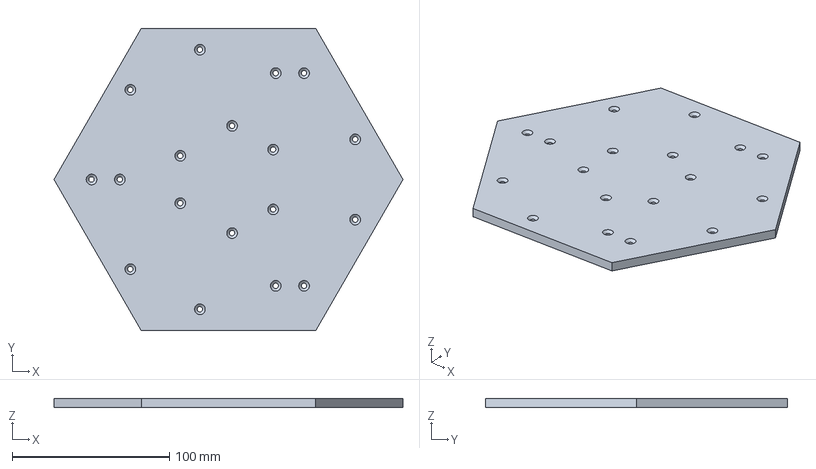
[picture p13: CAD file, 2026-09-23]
CAD/A10.step
221.7 x 192.0 x 6.00 mm

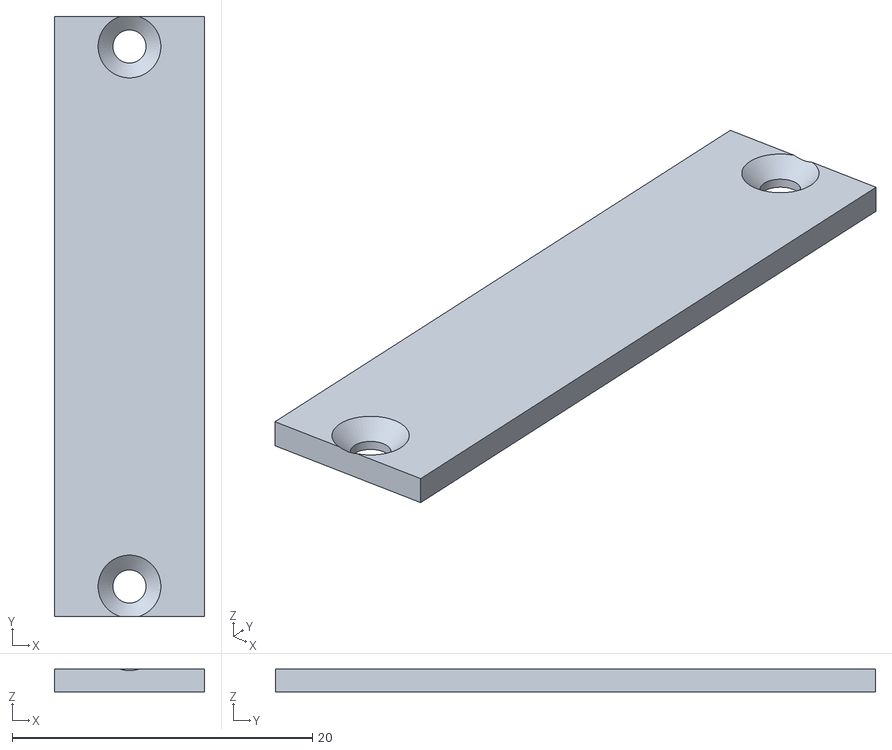
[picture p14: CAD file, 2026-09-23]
meshes/H05_1.stl
10.0 x 40.0 x 1.50

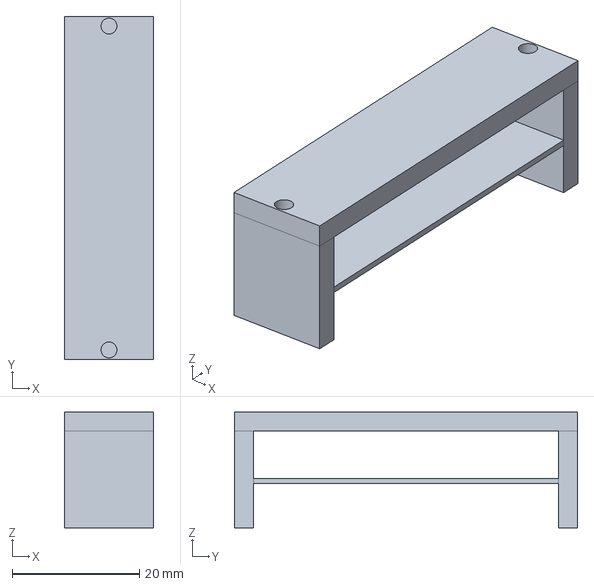
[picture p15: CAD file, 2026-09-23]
CAD/H07_1.step
14.0 x 54.0 x 18.3 mm

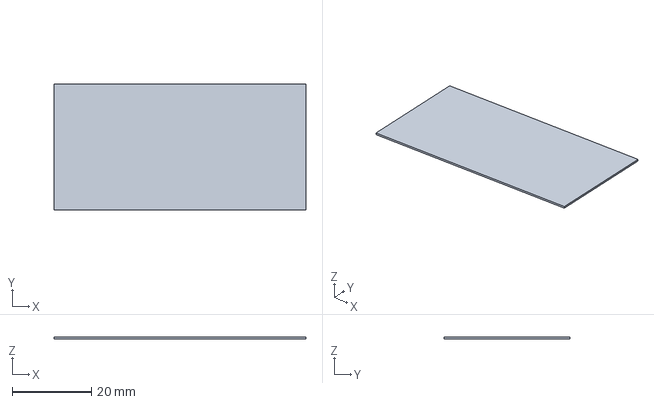
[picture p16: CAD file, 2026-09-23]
CAD/P01_1.step
63.5 x 31.8 x 0.51 mm

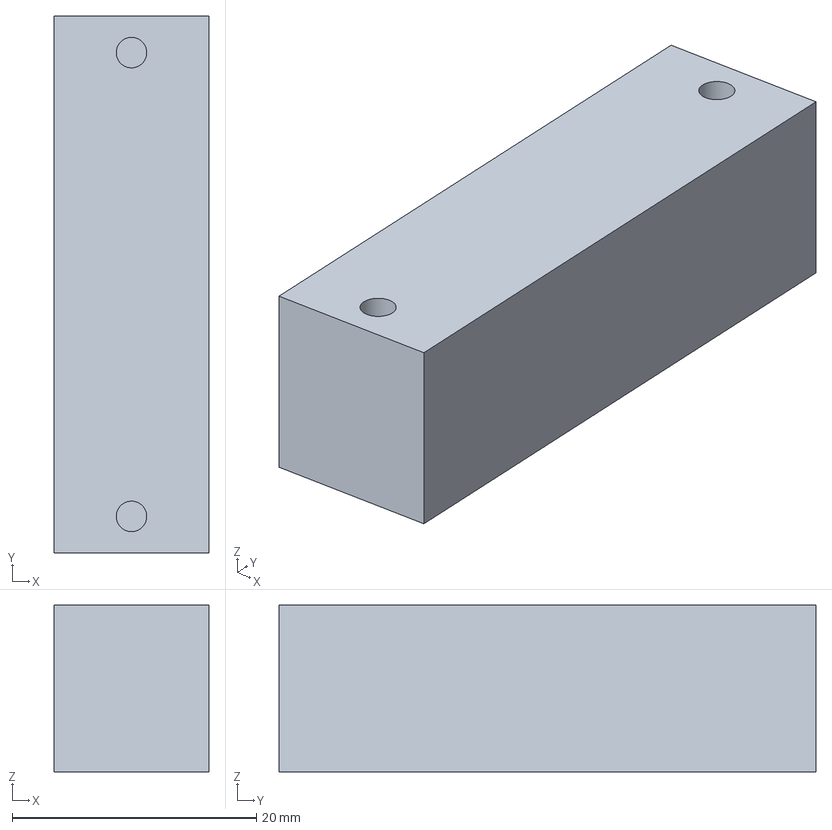
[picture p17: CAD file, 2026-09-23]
CAD/H01_1.step
12.7 x 44.0 x 13.6 mm

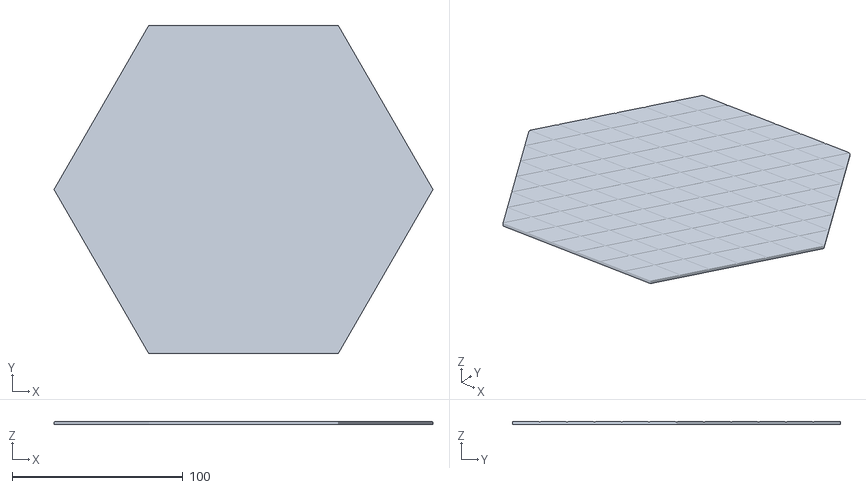
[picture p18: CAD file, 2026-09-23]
meshes/A11.stl
221.7 x 192.0 x 2.00

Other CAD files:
CAD/H02_1.step
meshes/A10.stl
meshes/E03.stl
CAD/G01_1.step
meshes/P01_1.stl
CAD/A01.step
CAD/A02.step
CAD/A11.step
CAD/Cover_Plate_Reference.dxf
CAD/E01.step
CAD/G02_1.step
CAD/G03_1.step
CAD/H05_1.step
CAD/H08_1.step
CAD/S01_1.step
meshes/A01.stl
meshes/E01.stl
meshes/G02_1.stl
meshes/G03_1.stl
meshes/H01_1.stl
meshes/H04_1.stl
meshes/H07_1.stl
meshes/S01_1.stl

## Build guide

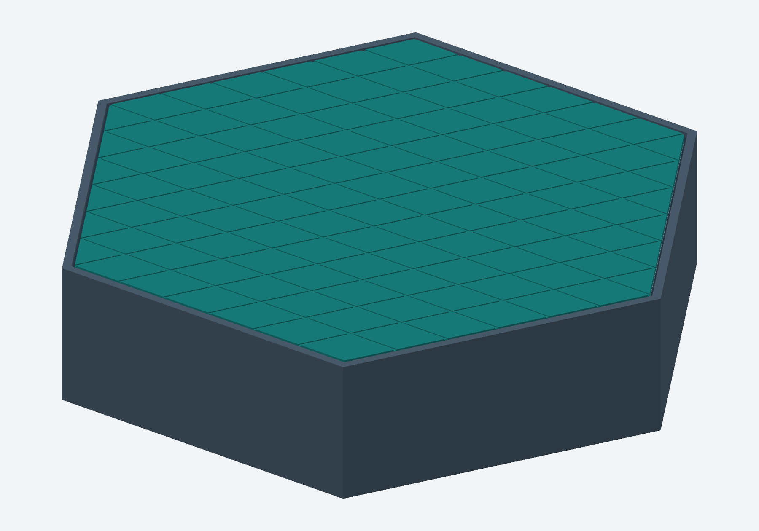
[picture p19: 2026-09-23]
figures/Tile_Assembled.png
